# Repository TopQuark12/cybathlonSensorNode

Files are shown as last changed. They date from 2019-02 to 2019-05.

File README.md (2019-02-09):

# IMU and magnetic encoder sensor node
This repositry stores PCB files and firmware for HKUST Cybathlon sensor node.  
Repositry created and maintained by Alex Wong.  
  
## Hardware  

### Function
Each sensor node is intended to contain either a ICM-20602 IMU or MA730 magnetic rotary encoder. It is also possible for one node to contain both sensors.  
The sensor nodes are designed to be mounted on various points on the exoskeleton to sense limb attitude or joint angle.  
  
### Communication
Sensor nodes communicate through a 1Mbaud CAN bus network, each node broadcasts sensor readings to the network.   
All sensor nodes should be daisy-chained with JST GH 8-pin cables for power and data.  
Termination connectors must be connected to both ends of the daisy chain to ensure signal integrity.  
Data from all the sensors can be read out at any one of the sensor nodes, through the on-board USB-C port and USB to serial converter.  
It is also possible for sensor nodes to log sensor or CAN bus data to the on-board SD-card slot.  
  
### Power  
Sensor nodes can either be powered through the two JST GH 8-pin connectors or through the USB type-C connector.  
Nominal voltage input range: 4.5v to 6v.  
All sensor nodes are protected from over voltage and reversed voltage, surviving from -64v to 64v (limited by testing method).  
Each sensor node is rated at 200mA in normal operation, and will draw at most 350mA at short circuit.  

## Software

### Dependencies
Build tool: GNU Make  
Tool Chain: arm-gcc-none-eabi  
HAL: STM32Cube (files included in repositry)  
Middlewares: freeRTOS, fatfs (files included in repositry)  

### Flashing and debugging
There are multiple options for flashing firmware and optionally debug the board.

1. On-board 1.27mm 2x5-pin SWD debug port (with SWO)  
   ARM debug probes (e.g. STLink, J-link, uLink etc.) can be connected to this port fo program and debug the on-board MCU. Segger J-Link and Segger Ozone is recommended.  
   
1. On-board USB type-C port and USB to serial converter  
   The USB to serial chip is connected to the USART1 port of the STM32F405RG MCU, allowing the MCU to be programmed through the USB port without additional hardware. To use this feature, set the on-board BOOT0 switch to 1, before pressing the reset button. Use software tools like the FLASHER-STM32 to flash binaries into the MCU. After flashing, set the on-board BOOT0 switch to 0, then reset the MCU and the new code will run. This method does not provide debugging capabilities.

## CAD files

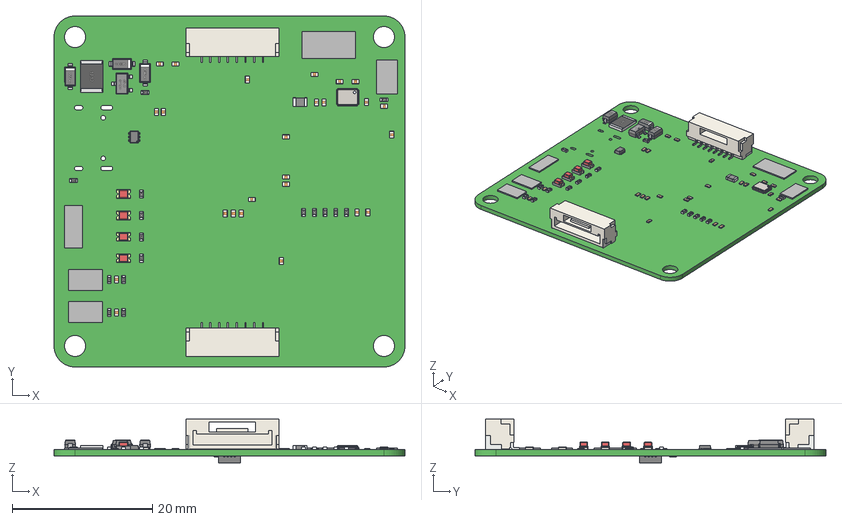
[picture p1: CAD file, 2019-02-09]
Hardware/ExoSensorNode.step
50.0 x 50.0 x 6.21 mm
Board
User_Library-3225-1
Extruded x 5
User_Library-RES_1005-0402 x 16
User_Library-led_0805 x 4
0402_SMD_Capacitor x 27
Open_CASCADE_STEP_translator_6.8_1.1 x 2
Open_CASCADE_STEP_translator_6.8_1.2.1 x 2
Thermal_Shape
Open_CASCADE_STEP_translator_6.8_1.4.1 x 16
SOT-23
JST_SM08B-GHS-TB x 2
L0805
R1812
SOD123 x 3
lead x 6

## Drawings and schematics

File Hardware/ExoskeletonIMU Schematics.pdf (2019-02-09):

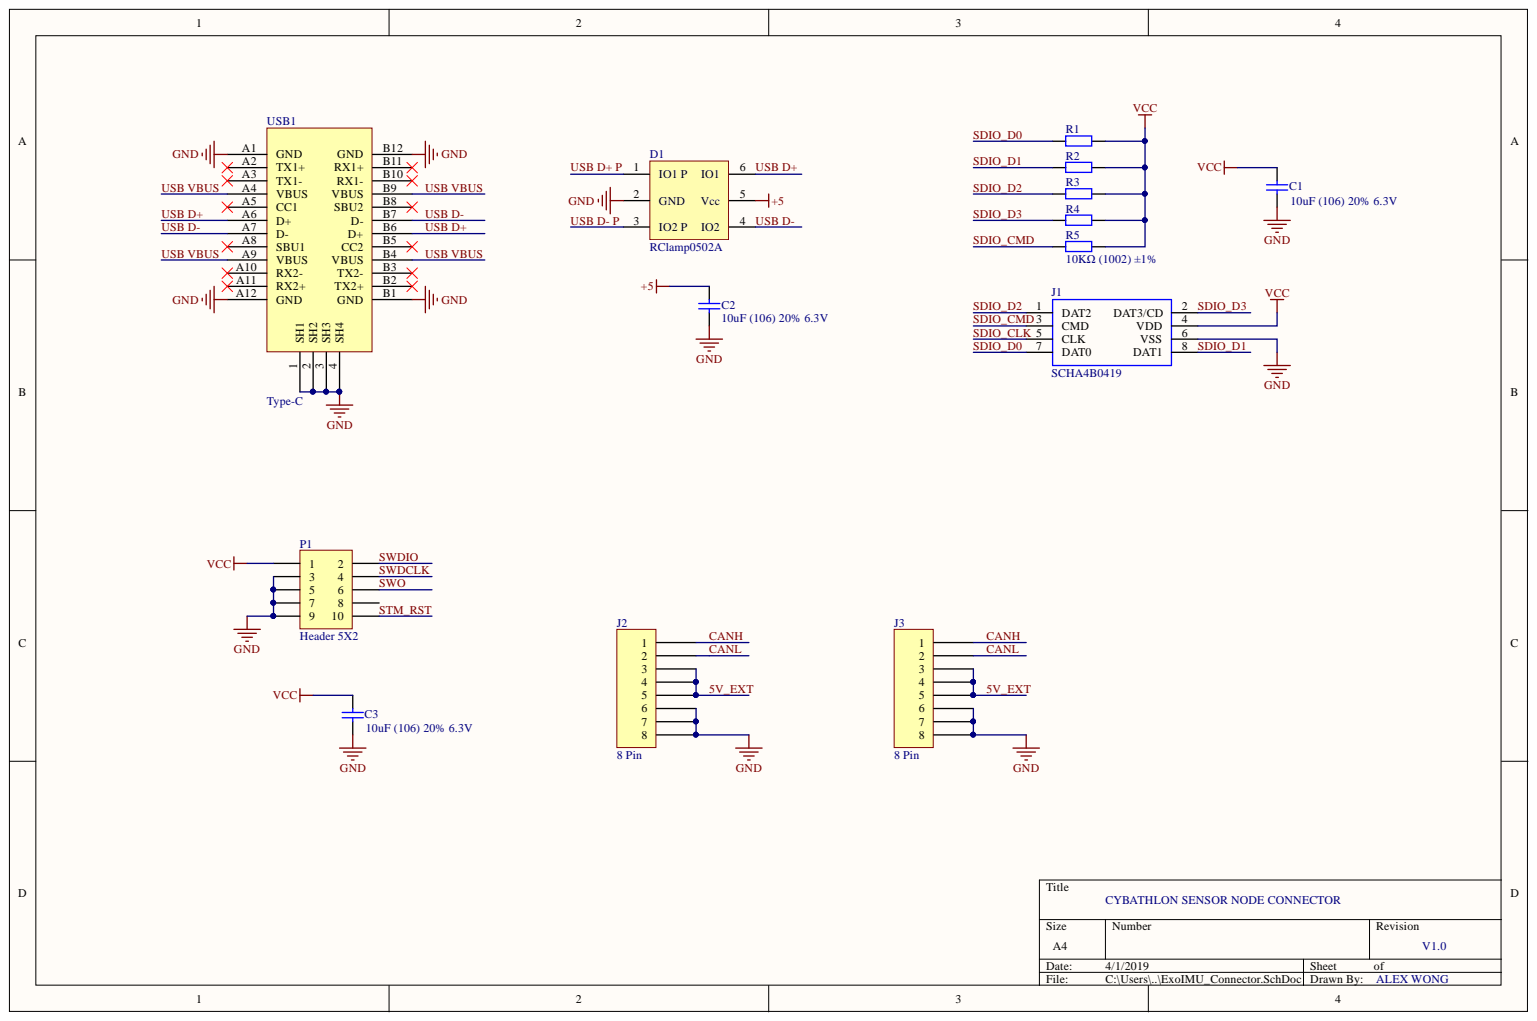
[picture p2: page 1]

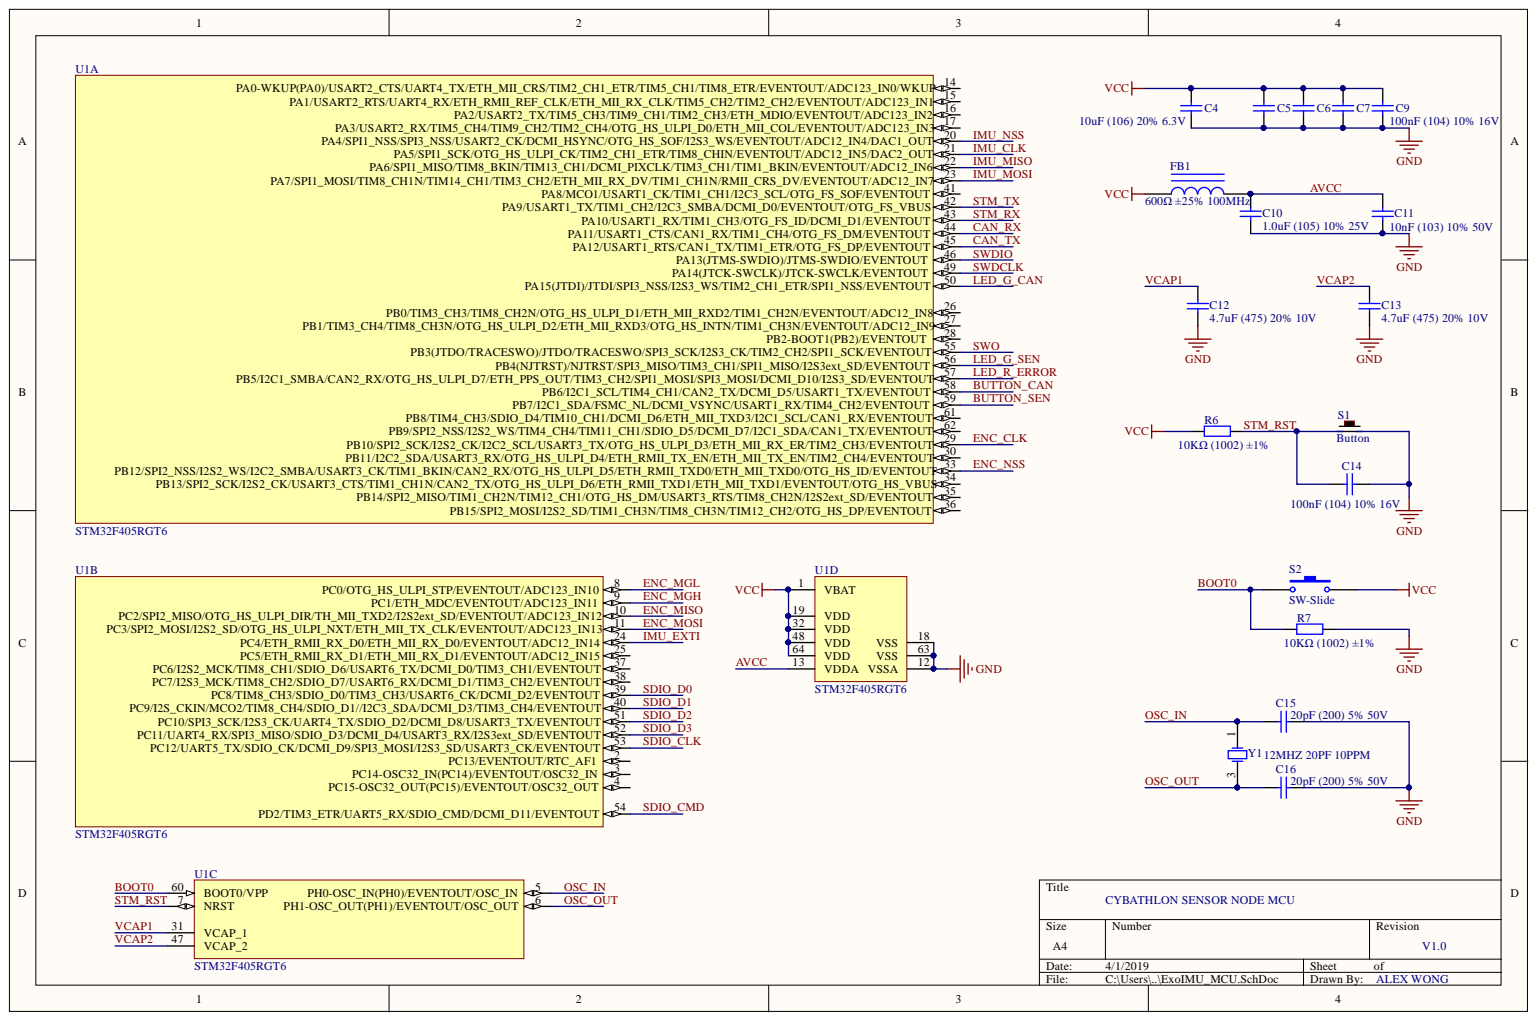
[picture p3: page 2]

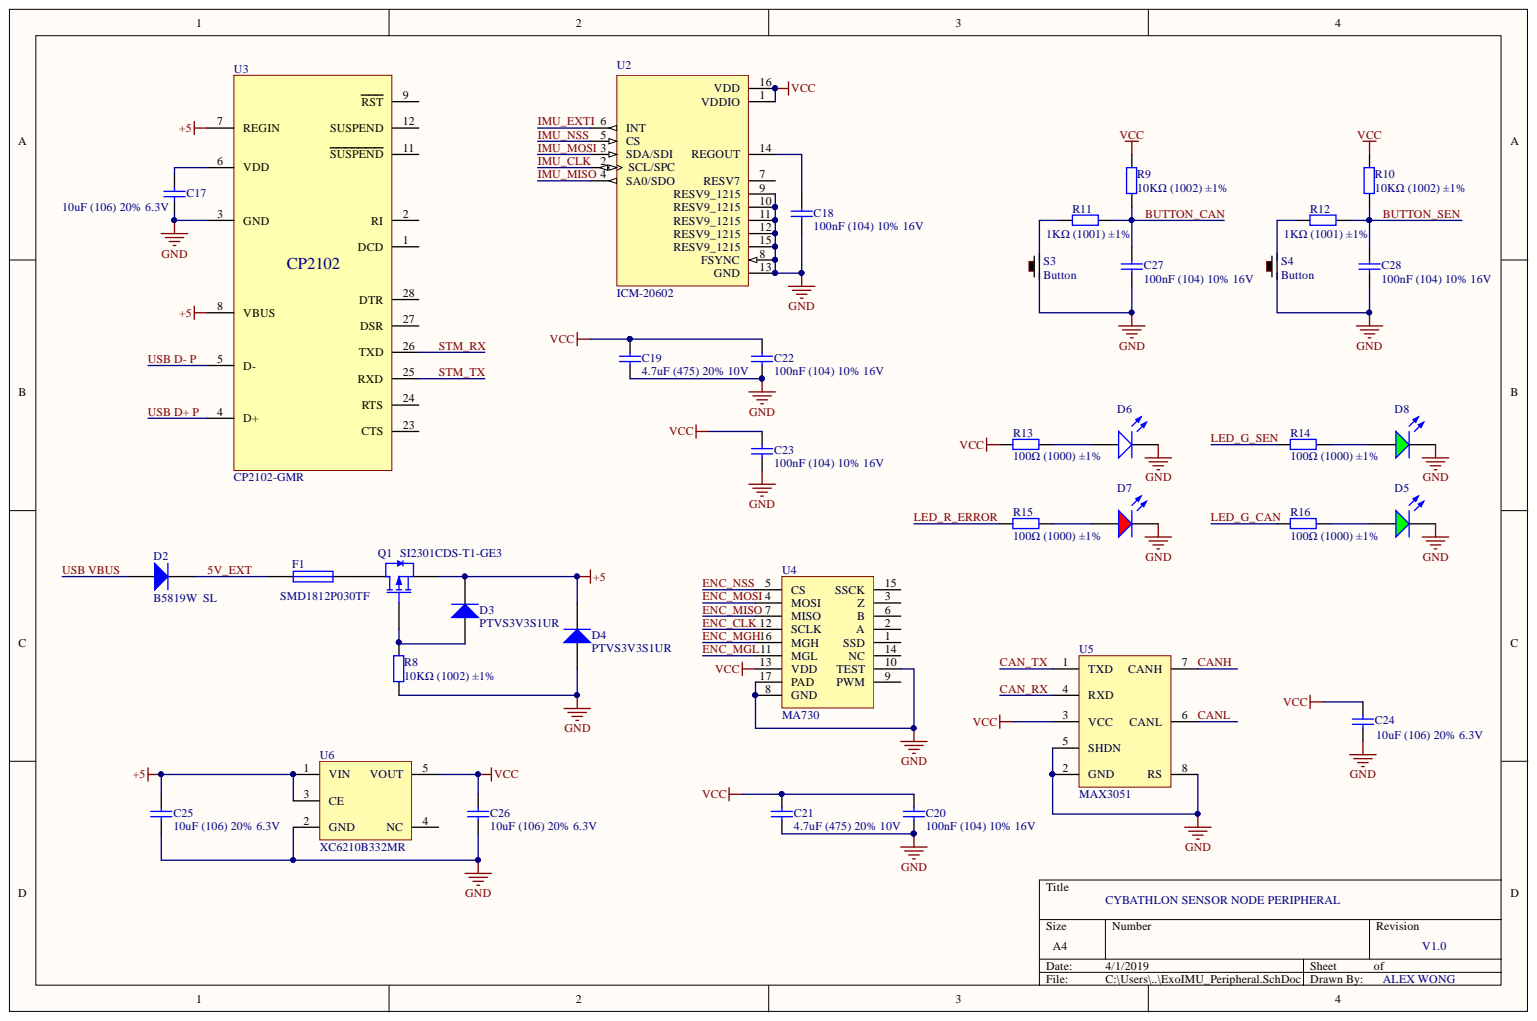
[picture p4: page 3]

CYBATHLON SENSOR NODE PERIPHERAL

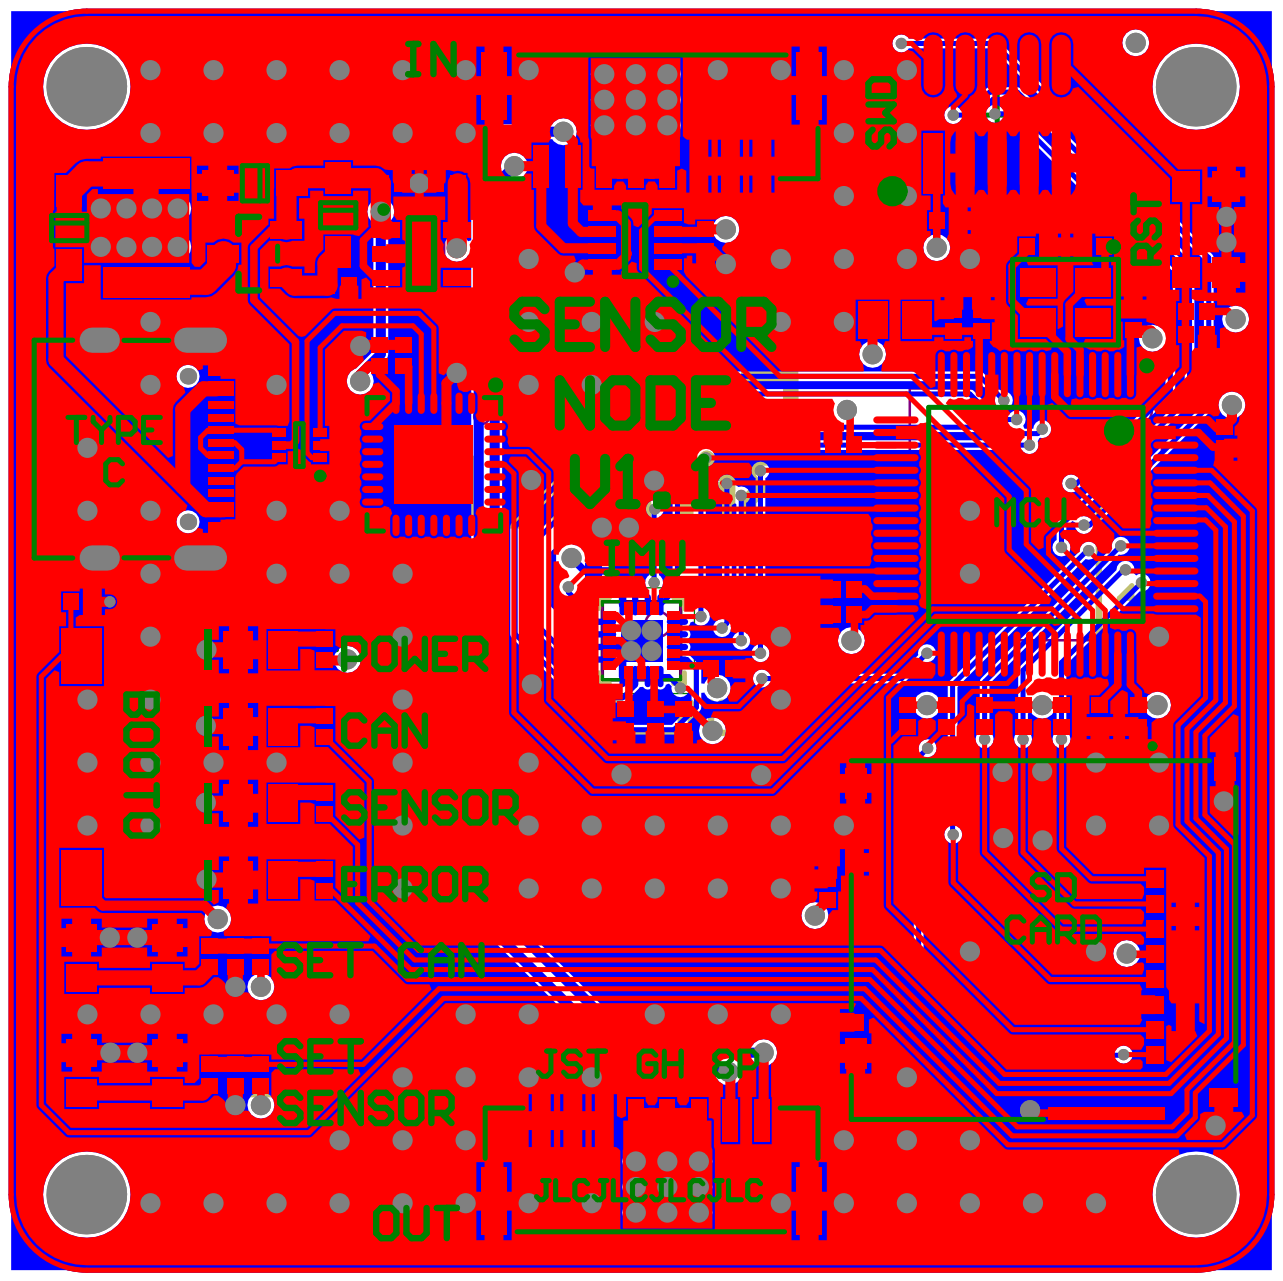
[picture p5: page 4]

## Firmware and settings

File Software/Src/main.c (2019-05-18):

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

/* Includes ------------------------------------------------------------------*/
#include "main.h"
#include "cmsis_os.h"
#include "can.h"
#include "dma.h"
#include "fatfs.h"
#include "sdio.h"
#include "spi.h"
#include "usart.h"
#include "gpio.h"

/* USER CODE BEGIN Includes */

#include "bsp_driver_sd.h"
#include "stm32f4xx_hal.h"
#include "fatfs.h"
#include "sdio.h"
#include "sd_card.h"
#include "flash.h"

/* USER CODE END Includes */


void SystemClock_Config(void);
void MX_FREERTOS_Init(void);
/**
  * @brief  The application entry point.
  * @retval int
  */
int main(void)
{
  /* MCU Configuration--------------------------------------------------------*/

  /* Reset of all peripherals, Initializes the Flash interface and the Systick. */
  HAL_Init();

  /* Configure the system clock */
  SystemClock_Config();

  /* Initialize all configured peripherals */
  MX_GPIO_Init();
  MX_DMA_Init();
  MX_CAN1_Init();
  MX_SDIO_SD_Init();
  MX_SPI1_Init();
  MX_USART1_UART_Init();
  MX_SPI2_Init();
  /* USER CODE BEGIN 2 */

  gFlashSaveFlag = FLASH_SAVE_READY;    //Setup flash parameter saving and loading
  flashLoad(NULL);                      //Load default set of parameters

  canIDInit();    // Initialize can ID

  /* USER CODE END 2 */

  /* Call init function for freertos objects (in freertos.c) */
  MX_FREERTOS_Init();

  /* Start scheduler */
  osKernelStart();
  
  /* We should never get here as control is now taken by the scheduler */

  /* Infinite loop */
  /* USER CODE BEGIN WHILE */
  sd_test();
  sd_test();
  sd_test();
  while (1)
  {
    /* USER CODE END WHILE */

    /* USER CODE BEGIN 3 */
  }
  /* USER CODE END 3 */
}

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
/**
  * @brief  Period elapsed callback in non blocking mode
  * @note   This function is called  when TIM6 interrupt took place, inside
  * HAL_TIM_IRQHandler(). It makes a direct call to HAL_IncTick() to increment
  * a global variable "uwTick" used as application time base.
  * @param  htim : TIM handle
  * @retval None
  */
void HAL_TIM_PeriodElapsedCallback(TIM_HandleTypeDef *htim)
{
  if (htim->Instance == TIM6) {
    HAL_IncTick();
  }
}

/**
  * @brief  This function is executed in case of error occurrence.
  * @retval None
  */
void Error_Handler(void)
{
  /* USER CODE BEGIN Error_Handler_Debug */
  /* User can add his own implementation to report the HAL error return state */

  /* USER CODE END Error_Handler_Debug */
}

#ifdef  USE_FULL_ASSERT
/**
  * @brief  Reports the name of the source file and the source line number
  *         where the assert_param error has occurred.
  * @param  file: pointer to the source file name
  * @param  line: assert_param error line source number
  * @retval None
  */
void assert_failed(uint8_t *file, uint32_t line)
{ 
  /* USER CODE BEGIN 6 */
  /* User can add his own implementation to report the file name and line number,
     tex: printf("Wrong parameters value: file %s on line %d\r\n", file, line) */
  /* USER CODE END 6 */
}
#endif /* USE_FULL_ASSERT */

/************************ (C) COPYRIGHT STMicroelectronics *****END OF FILE****/

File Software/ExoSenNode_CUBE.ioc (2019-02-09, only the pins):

Mcu.UserName=STM32F405RGTx
PA10.Signal=USART1_RX
PA11.Signal=CAN1_RX
PA12.Signal=CAN1_TX
PA13.Signal=SYS_JTMS-SWDIO
PA14.Signal=SYS_JTCK-SWCLK
PA15.GPIO_Label=LED_G_CAN
PA15.Signal=GPIO_Output
PA4.GPIO_Label=IMU_CS
PA4.Signal=GPIO_Output
PA5.Signal=SPI1_SCK
PA6.Signal=SPI1_MISO
PA7.Signal=SPI1_MOSI
PA9.Signal=USART1_TX
PB10.Signal=SPI2_SCK
PB12.GPIO_Label=SPI2_CS
PB12.Signal=GPIO_Output
PB3.Signal=SYS_JTDO-SWO
PB4.GPIO_Label=LED_G_SEN
PB4.Signal=GPIO_Output
PB5.GPIO_Label=LED_R_ERROR
PB5.Signal=GPIO_Output
PB6.GPIO_Label=BUTTON_CAN
PB6.Signal=GPIO_Input
PB7.GPIO_Label=BUTTON_SEN
PB7.Signal=GPIO_Input
PC0.GPIO_Label=ENC_MGL
PC0.Signal=GPXTI0
PC1.GPIO_Label=ENC_MGH
PC1.Signal=GPXTI1
PC10.Signal=SDIO_D2
PC11.Signal=SDIO_D3
PC12.Signal=SDIO_CK
PC2.Signal=SPI2_MISO
PC3.Signal=SPI2_MOSI
PC4.GPIO_Label=IMU_EXTI
PC4.Signal=GPXTI4
PC8.Signal=SDIO_D0
PC9.Signal=SDIO_D1
PD2.Signal=SDIO_CMD
PH0-OSC_IN.Signal=RCC_OSC_IN
PH1-OSC_OUT.Signal=RCC_OSC_OUT

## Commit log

2019-01-04 added schematics and step files
    [ExoSensorNode.step]
2019-01-04 software init commit, MCU and LED works
2019-01-05 Encoder works
2019-01-05 IMU and encoder working
2019-01-05 IMU, encoder and CAN working
2019-01-06 IMU, encoder, CAN, USB flashing and SD card working
2019-02-04 IMU SPI driver stable, accel X data seems wrong
    [ExoSenNode_CUBE.ioc, ICM20602.c, ICM20602.h]
2019-02-06 IMU driver stable
2019-02-07 init commit, flash save not working yet
    [ICM20602.c, ICM20602.h, flash.c]
2019-02-09 apply reset and offset at startup
    [ICM20602.c, ICM20602.h]
2019-02-09 calibration works, updated data structures
2019-02-18 fix wrong calculation on icm20602Update
    [ICM20602.c]
2019-03-15 fix can bandwidth problem
    [ICM20602.h, can.c, main.c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]

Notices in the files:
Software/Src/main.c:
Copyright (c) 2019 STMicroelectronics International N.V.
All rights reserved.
